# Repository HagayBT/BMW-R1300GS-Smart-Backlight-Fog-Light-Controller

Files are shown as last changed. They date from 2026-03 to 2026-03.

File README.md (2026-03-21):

# BMW R1300GS Smart Backlight & Fog Light Controller — EasierCan v2.0

A fully custom, CAN-bus-integrated lighting controller for the BMW R1300GS motorcycle. Reads factory CAN bus signals directly from the XDWA connector to control rear LED strips, fog lights, and an air horn — no wire cutting or relay splicing into the original harness.

Fully configurable over Bluetooth using a mobile-friendly Web Bluetooth UI — no app install required.

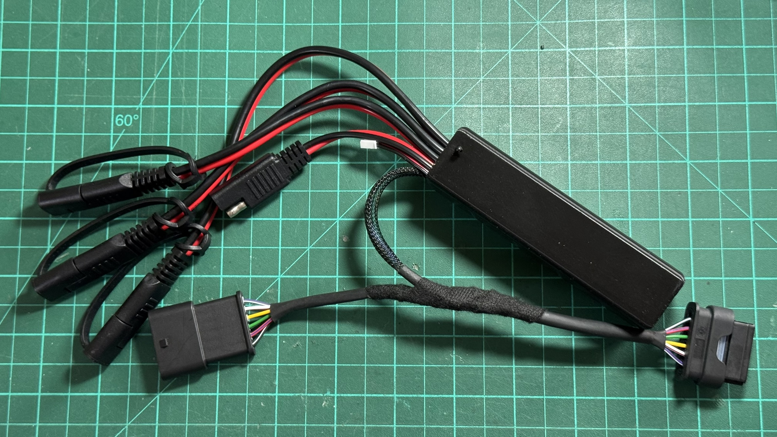
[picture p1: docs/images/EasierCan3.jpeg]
Project Banner


---

## ✨ Features

### Lighting & Outputs
- **Configurable LED strips** — 9× SK6812 RGBW LEDs per side, split into independent brake zone (first N LEDs) and indicator zone (remaining LEDs)
- **Configurable MOSFET outputs** — 3× isolated 12V outputs for fog lights and air horn
- **Wave sequential turn signals** — indicator LEDs fill sequentially left-to-right in amber
- **Blink turn signals** — standard ~1.5 Hz amber flash (50% duty cycle)
- **Brake light** — brake zone shows dim red at idle, full bright red when braking
- **Strobe mode** — triggered by triple high-beam flash within a configurable window
- **Startup animations** — 10 selectable boot animations (Night Rider, Split/BMW Sweep, Converge & Explode, Heartbeat, Comet/Meteor, Stack/Tetris, Twinkle Fade-In, Thunder, Breathe/Pulse, Ping Pong)

### Configuration
- **BLE wireless configuration** — connect from Chrome on any phone or desktop, no app needed
- **Per-output triggers** — each output has two independent event slots (ev1 / ev2), each with its own trigger, action, and delay
- **Configurable actions** — None, On, Off, Strobe, Blink; plus Wave for LED strips
- **Configurable triggers** — Brake, Signal Left, Signal Right, High Beam, Engine Running, Power On, Hazard, High Beam ×3, Horn
- **Configurable delay** — action starts only after trigger has been active for N seconds
- **NVS persistence** — all settings survive power loss, stored in ESP32 flash
- **Auto-read on connect** — UI loads device config automatically when BLE connects

### Diagnostics
- **Test Events panel** — simulate any CAN signal from the UI without touching the bike
- **Serial diagnostics** — 2-second heartbeat via USB: CAN state, RPM, error counters, signal states
- **CAN bus isolated** — listen-only mode, never transmits to the bus

---

## 🧰 Bill of Materials

| # | Component | Notes |
|---|---|---|
| 1 | Arduino Nano ESP32 | Main controller (ESP32-S3) |
| 1 | SN65HVD230 CAN Bus Transceiver | 3.3V logic, connects to XDWA |
| 1 | 872-861-501 6P OBD Connector (BMW/VW/MB) | Plugs into R1300GS XDWA port |
| 1 | DC-DC Buck Converter 5V–30V → 5V 3A | Powers Arduino + LEDs from 12V bike battery |
| 3 | LR7843 Isolated MOSFET Module (HW-532B) | Fog light left, fog light right, air horn |
| 18 | SK6812 RGBW LED (addressable) | 9 per side, rear tail/turn strip |
| 1 | Silicone Wire 22 AWG | All signal and power wiring |
| 3 | 3D Printed Parts | BackLightBody, BackLightRod, BackLightScreen |

---

## 📐 Wiring Diagram

### System Overview

```
BMW R1300GS XDWA Connector          Controller Box
  │
  ├── Pin 2  (Ground) ─────────────► Common GND (Buck IN– / Arduino GND / SN65HVD230 GND)
  ├── Pin 3  (12V ACC) ────────────► DC-DC Buck Converter IN+
  ├── Pin 4  (CAN Low) ────────────► SN65HVD230 CANL
  └── Pin 5  (CAN High) ───────────► SN65HVD230 CANH
                                          │
                              SN65HVD230 TX/RX
                                          │
                                    Arduino Nano ESP32  ◄── Buck OUT+ 5V
                                          │
                        ┌─────────────────┼─────────────────┐
                        ▼                 ▼                  ▼
                  MOSFET #1          MOSFET #2          MOSFET #3
                  Fog Light LEFT     Air Horn           Fog Light RIGHT
                        │                                    │
                        ▼                                    ▼
                   Fog Light L                         Fog Light R

            ┌─────────────────────────────────┐
            ▼                                 ▼
     LED Strip LEFT                   LED Strip RIGHT
     (9× SK6812 RGBW)                (9× SK6812 RGBW)
     D3 / GPIO_6                     D5 / GPIO_8
```

### Arduino Nano ESP32 Pin Assignment

| Arduino Pin | GPIO | Connected To |
|---|---|---|
| D4 | GPIO_7 | SN65HVD230 TX (CAN TX) |
| D6 | GPIO_9 | SN65HVD230 RX (CAN RX) |
| A1 | GPIO_2 | MOSFET #1 — Fog Light RIGHT (PWM in) |
| A5 | GPIO_12 | MOSFET #2 — Fog Light LEFT (PWM in) |
| A3 | GPIO_4 | MOSFET #3 — Air Horn (PWM in) |
| D3 | GPIO_6 | SK6812 Data — LEFT strip |
| D5 | GPIO_8 | SK6812 Data — RIGHT strip |

### MOSFET Module Wiring (each of 3 modules)

| MOSFET Terminal | Connect To |
|---|---|
| **PWM** (signal) | Arduino output pin (see table above) |
| **GND** (signal) | Arduino GND |
| **+** (load) | Motorcycle 12V positive |
| **LOAD** | Fog light / horn positive wire |
| **–** (load) | Motorcycle chassis ground |

> The fog light / horn negative wire also connects to chassis ground directly.
> Signal GND and Load GND are **isolated** by the onboard optocoupler — this is intentional.

### XDWA Connector Pinout (BMW R1300GS)

The 6P XDWA connector is the only connection needed to the bike. Use the 872-861-501 mating connector.

| Pin | Signal | Voltage | Used |
|-----|---|---|---|
| 1 | 12V Constant | 12V | — (not used) |
| 2 | Ground | 0V | ✅ Common ground |
| 3 | 12V ACC (after ignition switch) | 12V | ✅ Power input |
| 4 | CAN Low | ~2.7V | ✅ CAN bus |
| 5 | CAN High | ~2.3V | ✅ CAN bus |
| 6 | Empty | — | — |

> ⚠️ Note: CAN High/Low voltages on this bike are inverted from typical convention (High ~2.3V, Low ~2.7V). If you see no CAN traffic, try swapping CANH/CANL wires first.

### SN65HVD230 CAN Transceiver Wiring

| Transceiver Pin | Connect To |
|---|---|
| VCC | Arduino 3.3V output |
| GND | XDWA Pin 2 (common ground) |
| TX | Arduino D4 (GPIO_7) |
| RX | Arduino D6 (GPIO_9) |
| CANH | XDWA Pin 5 |
| CANL | XDWA Pin 4 |

> The SN65HVD230 runs at 3.3V logic and is directly compatible with the ESP32. Power it from the Arduino's **3.3V output pin**, not from the buck converter.
> Do **not** add a 120Ω termination resistor — the bike's bus is already terminated.

### DC-DC Buck Converter Wiring

| Buck Converter | Connect To |
|---|---|
| IN+ | XDWA Pin 3 (12V ACC) |
| IN– | XDWA Pin 2 (Ground) |
| OUT+ (5V) | Arduino 5V pin + SK6812 strip 5V power |
| OUT– | Arduino GND + SK6812 strip GND |

> Set the output to **5V** before connecting anything. The SK6812 strips and Arduino Nano ESP32 both run on 5V.

---

## 📡 CAN Bus Messages (BMW R1300GS)

These CAN IDs were identified on the R1300GS XDWA connector at **500 kbps**.

| CAN ID | Purpose | Relevant Byte/Bit |
|---|---|---|
| `0x10C` | Engine RPM (BMSK module) | `(data[2]×256 + data[1]) / 4` = RPM |
| `0x2D0` | High beam flash | Byte 6, bit 4 = 0 when flashed |
| `0x2D2` | Switches | Byte 0, bit 2 = Left signal |
| | | Byte 0, bit 3 = Right signal |
| | | Byte 0, bit 5 = Brake |

> ⚠️ These IDs were reverse-engineered on a specific R1300GS. Confirm with a CAN scanner on your own bike before trusting them. They may vary by model year or spec.

---

## 💡 LED Strip Layout

Each side has **9× SK6812 RGBW LEDs**, split into two independently controlled zones (counts are configurable):

```
[ 0 ][ 1 ][ 2 ]       — Brake Zone  (default 3 LEDs, controlled by Event 1)
[ 3 ][ 4 ][ 5 ][ 6 ][ 7 ][ 8 ] — Indicator Zone (remaining LEDs, controlled by Event 2)
```

**Brake zone default behavior:** dim red `(60, 0, 0, 0)` at idle → full red `(255, 0, 0, 0)` when brake trigger fires
**Indicator zone default behavior:** amber sequential wave `(255, 50, 0, 0)` when signal trigger fires

---

## ⚙️ Output Configuration

Each of the 5 outputs has **two independent event slots** (Ev1 / Ev2). Each slot configures:

| Field | Options |
|---|---|
| **Trigger** | None, Brake, Signal Left, Signal Right, High Beam, Engine Running, Power On, Hazard, High Beam ×3, Horn |
| **Action** | None, On, Off, Blink, Strobe, Wave *(LED strips only)* |
| **Delay** | 0, 1, 2, 4, 8, 16, 32, 64, 128 seconds |

For **LED strips**: Ev1 drives the brake zone, Ev2 drives the indicator zone independently.
For **12V MOSFET outputs**: Ev2 takes priority over Ev1 when both triggers are active.

### Default Output Configuration

| Output | Function | Ev1 Trigger | Ev1 Action | Ev1 Delay | Ev2 Trigger | Ev2 Action | Ev2 Delay |
|---|---|---|---|---|---|---|---|
| LED Left Strip | LED Strip | Brake | On | 0s | Signal Left | Wave | 0s |
| LED Right Strip | LED Strip | Brake | On | 0s | Signal Right | Wave | 0s |
| 12v Output 1 | Fog Light Left | Engine Running | On | 5s | High Beam ×3 | Strobe | 0s |
| 12v Output 2 | Air Horn | Horn | On | 1s | — | — | — |
| 12v Output 3 | Fog Light Right | Engine Running | On | 5s | High Beam ×3 | Strobe | 0s |

---

## 📱 BLE Configuration UI

Open `EasierCan.html` in **Chrome** (desktop or Android) — no app install required.

### Connecting

1. Power on the controller (bike ignition on, or bench power)
2. Open `EasierCan.html` in Chrome
3. Press **Connect** and select **EasierCan** from the Bluetooth popup
4. All current device settings are loaded automatically

### Sections

| Section | Description |
|---|---|
| **Startup Sequence** | Choose the boot animation; Send/Read from device |
| **Test Events** | Simulate CAN signals (brake, signals, high beam, etc.) without the bike |
| **Output Configuration** | Configure triggers, actions, and delays per output |
| **Advanced Variables** | LED counts, RPM threshold, strobe timing, wave timing |

### Test Events Panel

| Button | Type | Simulates |
|---|---|---|
| Power On | Toggle | Runs startup animation |
| Engine Running | Toggle | Sets engine-running state |
| Hazard | Toggle | Both signals active |
| Horn | Momentary | 300ms horn pulse |
| Signal Left | Hold | Left signal while held |
| High Beam | Hold | High beam while held |
| Brake | Hold | Brake signal while held |
| Signal Right | Hold | Right signal while held |

---

## 🚀 Startup Animations

| # | Name | Description |
|---|---|---|
| 0 | None | No animation |
| 1 | Random | Picks one of the below at random |
| 2 | Night Rider | Red scanner sweep (Knight Rider style) |
| 3 | Split / BMW Sweep | Warm-white comet sweeps outward from center |
| 4 | Converge & Explode | Amber heads race to center, then white burst |
| 5 | Heartbeat | Lub-dub red pulse × 3 |
| 6 | Comet / Meteor | Warm-white head with long amber-to-red tail |
| 7 | Stack (Tetris) | LEDs shoot and stack into a red column |
| 8 | Twinkle Fade-In | Random warm-white sparkles solidify to red |
| 9 | Thunder | Random white flashes, then dim red bloom |
| 10 | Breathe / Pulse | Slow sine-like red fade × 3 cycles |
| 11 | Ping Pong | Orange dot bounces end-to-end, accelerating |

---

## 🛠️ Software Setup

### Dependencies

Install via Arduino Library Manager:

- [`Adafruit NeoPixel`](https://github.com/adafruit/Adafruit_NeoPixel)
- [`ArduinoBLE`](https://github.com/arduino-libraries/ArduinoBLE)
- [`ArduinoJson`](https://arduinojson.org/) (>= 6.21)
- ESP32 Arduino Core by Espressif (includes `driver/twai.h` — no separate install needed)

### Board Setup

1. Install **Arduino ESP32 core** in Arduino IDE (Board Manager → search "esp32" by Espressif)
2. Select board: **Arduino Nano ESP32**
3. Upload `EasierCan/EasierCan.ino`

### First Boot

Open Serial Monitor at **115200 baud**. You will see:

```
========================================
     BMW R1300GS  —  EasierCan  v2
========================================
[NVS] No saved config — using defaults.
[BLE] Advertising as "EasierCan"
```

Every 2 seconds a diagnostic report prints:

```
--- DIAGNOSTIC ---
CAN msg/2s: 847
RX errors:  0
CAN state:  RUNNING
RPM: 1250  Eng: ON  Str: off  Brk: off  L: off  R: off  Horn: off
[BLE] Advertising
------------------
```

If `CAN msg/2s: 0` appears, check wiring and ensure ignition is ON.

---

## 🔒 Safety Notes

- This device **reads** CAN bus only — it never transmits. It cannot interfere with bike ECU operation.
- Always fuse the 12V input line (suggest 5A inline fuse).
- The LR7843 MOSFET modules support up to 15A continuous — more than enough for fog lights and a horn.
- Test all connections on the bench before installing on the bike.
- Use the **Test Events** panel in the UI to verify output behaviour on the bench.

---

## 📁 Repository Structure

```
/
├── EasierCan/
│   ├── EasierCan.ino       # Main Arduino sketch
│   └── EasierCan.html      # Web Bluetooth configuration UI (open in Chrome)
├── README.md
├── STL/
│   ├── BackLightBody.stl
│   ├── BackLightRod.stl
│   └── BackLightScreen.stl
└── docs/
    └── images/
```

---

## 📜 License

MIT License — free to use, modify, and share. Credit appreciated!

---

## 🙏 Contributing

Found a different CAN ID on your R1300GS? Discovered a bug? PRs and Issues are welcome!

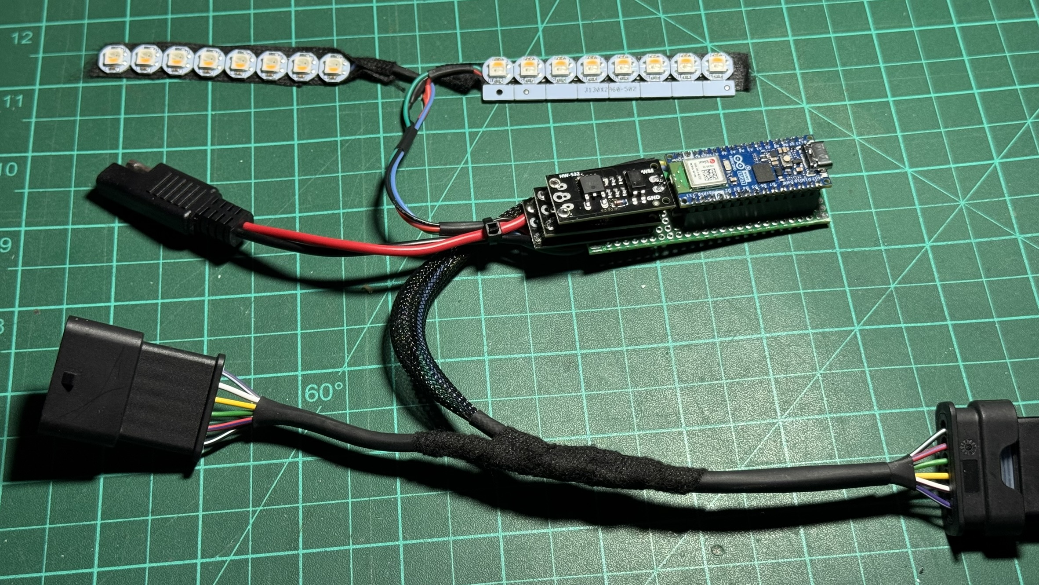
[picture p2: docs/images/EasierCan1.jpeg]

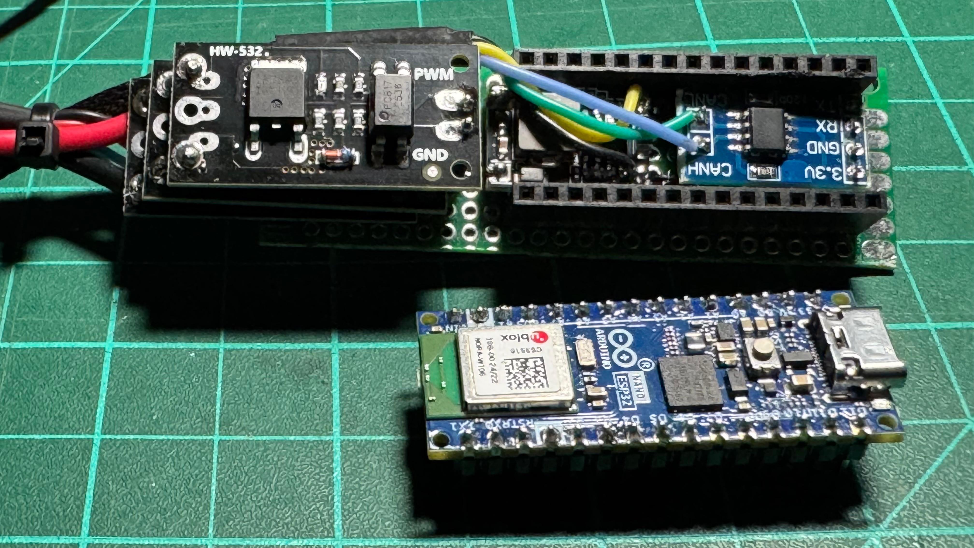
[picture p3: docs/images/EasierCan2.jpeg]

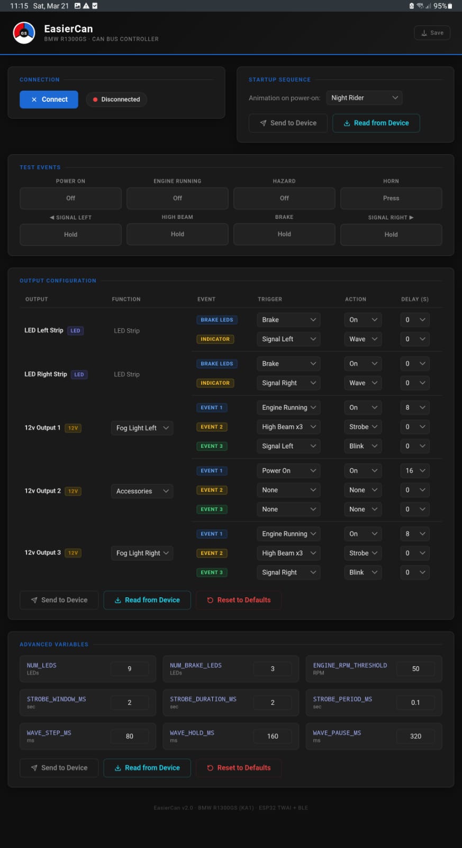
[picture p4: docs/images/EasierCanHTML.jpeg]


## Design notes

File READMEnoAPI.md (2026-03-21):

# BMW R1300GS Smart Backlight & Fog Light Controller

A fully custom, CAN-bus-integrated lighting controller for the BMW R1300GS motorcycle. Reads factory CAN bus signals directly from the XDWA connector to control rear LED strips, fog lights, and an air horn — no wire cutting or relay splicing into the original harness.

Project Banner

---

## ✨ Features

- **Wave-style sequential turn signals** — 9× SK6812 RGBW LEDs per side, filling left-to-right/right-to-left in sequence
- **Brake light** — first 3 LEDs on each strip dim red at idle, full bright red when braking
- **Fog light control** — left and right fog lights via MOSFET switches, auto-enable 10 seconds after engine start
- **Fog turn-signal blink** — fog lights blink in sync with the active turn signal
- **Emergency strobe** — triple-press the high-beam flash to trigger a 5-second full strobe on both fog lights
- **Air horn output** — third MOSFET reserved for future air horn
- **Knight Rider startup animation** — red sweep across all 18 LEDs on boot
- **Serial diagnostics** — 2-second heartbeat report via USB: CAN bus health, error counters, state summary
- **CAN bus isolated** — uses SN65HVD230 transceiver; reads-only, never writes to the bus

---

## 🧰 Bill of Materials

| # | Component | Notes |
|---|---|---|
| 1 | Arduino Nano ESP32 | Main controller |
| 1 | SN65HVD230 CAN Bus Transceiver | 3.3V logic, connects to XDWA |
| 1 | 872-861-501 6P OBD Connector (BMW/VW/MB) | Plugs into R1300GS XDWA port |
| 1 | DC-DC Buck Converter 5V–30V → 5V 3A | Powers Arduino + LEDs from 12V bike battery |
| 3 | LR7843 Isolated MOSFET Module (HW-532B) | Fog light left, fog light right, air horn |
| 18 | SK6812 RGBW LED (addressable) | 9 per side, rear tail/turn strip |
| 1 | Silicone Wire 22 AWG | All signal and power wiring |
| 3 | 3D Printed Parts | BackLightBody, BackLightRod, BackLightScreen |

---

## 📐 Wiring Diagram

### System Overview

```
BMW R1300GS XDWA Connector          Controller Box
  │
  ├── Pin 2  (Ground) ─────────────► Common GND (Buck IN– / Arduino GND / SN65HVD230 GND)
  ├── Pin 3  (12V ACC) ────────────► DC-DC Buck Converter IN+
  ├── Pin 4  (CAN Low) ────────────► SN65HVD230 CANL
  └── Pin 5  (CAN High) ───────────► SN65HVD230 CANH
                                          │
                              SN65HVD230 TX/RX
                                          │
                                    Arduino Nano ESP32  ◄── Buck OUT+ 5V
                                          │
                        ┌─────────────────┼─────────────────┐
                        ▼                 ▼                  ▼
                  MOSFET #1          MOSFET #2          MOSFET #3
                  Fog Light LEFT     Fog Light RIGHT     Air Horn
                        │                 │
                        ▼                 ▼
                   Fog Light L       Fog Light R
                                          
            ┌─────────────────────────────────┐
            ▼                                 ▼
     LED Strip LEFT                   LED Strip RIGHT
     (9× SK6812 RGBW)                (9× SK6812 RGBW)
     D3 / GPIO_6                     D5 / GPIO_8
```

### Arduino Nano ESP32 Pin Assignment

| Arduino Pin | GPIO | Connected To |
|---|---|---|
| D4 | GPIO_7 | SN65HVD230 TX (CAN TX) |
| D6 | GPIO_9 | SN65HVD230 RX (CAN RX) |
| A1 | GPIO_2 | MOSFET #1 — Fog Light RIGHT (PWM in) |
| A5 | GPIO_3 | MOSFET #2 — Fog Light LEFT (PWM in) |
| A3 | GPIO_4 | MOSFET #3 — Air Horn (PWM in) |
| D3 | GPIO_6 | SK6812 Data — LEFT strip |
| D5 | GPIO_8 | SK6812 Data — RIGHT strip |

### MOSFET Module Wiring (each of 3 modules)

| MOSFET Terminal | Connect To |
|---|---|
| **PWM** (signal) | Arduino output pin (see table above) |
| **GND** (signal) | Arduino GND |
| **+** (load) | Motorcycle 12V positive |
| **LOAD** | Fog light / horn positive wire |
| **–** (load) | Motorcycle chassis ground |

> The fog light / horn negative wire also connects to chassis ground directly.
> Signal GND and Load GND are **isolated** by the onboard optocoupler — this is intentional.

### XDWA Connector Pinout (BMW R1300GS)

The 6P XDWA connector is the only connection needed to the bike. Use the 872-861-501 mating connector.

| Pin | Signal | Voltage | Used |
|-----|---|---|---|
| 1 | 12V Constant | 12V | — (not used) |
| 2 | Ground | 0V | ✅ Common ground |
| 3 | 12V ACC (after ignition switch) | 12V | ✅ Power input |
| 4 | CAN Low | ~2.7V | ✅ CAN bus |
| 5 | CAN High | ~2.3V | ✅ CAN bus |
| 6 | Empty | — | — |

> ⚠️ Note: CAN High/Low voltages on this bike are inverted from typical convention (High ~2.3V, Low ~2.7V). If you see no CAN traffic, try swapping CANH/CANL wires first.

### XDWA → Controller Connections (as wired)

| XDWA Pin | Signal | Connect To |
|---|---|---|
| Pin 2 | Ground | DC-DC Buck IN– **and** Arduino GND **and** SN65HVD230 GND |
| Pin 3 | 12V ACC | DC-DC Buck IN+ |
| Pin 4 | CAN Low | SN65HVD230 CANL |
| Pin 5 | CAN High | SN65HVD230 CANH |

### SN65HVD230 CAN Transceiver Wiring

| Transceiver Pin | Connect To |
|---|---|
| VCC | Arduino 3.3V output |
| GND | XDWA Pin 2 (common ground) |
| TX | Arduino D4 (GPIO_7) |
| RX | Arduino D6 (GPIO_9) |
| CANH | XDWA Pin 5 |
| CANL | XDWA Pin 4 |

> The SN65HVD230 runs at 3.3V logic and is directly compatible with the ESP32. Power it from the Arduino's **3.3V output pin**, not from the buck converter.
> Do **not** add a 120Ω termination resistor — the bike's bus is already terminated. If you see RX errors, try swapping CANH/CANL or adding one and see if it improves.

### DC-DC Buck Converter Wiring

| Buck Converter | Connect To |
|---|---|
| IN+ | XDWA Pin 3 (12V ACC) |
| IN– | XDWA Pin 2 (Ground) |
| OUT+ (5V) | Arduino 5V pin + SK6812 strip 5V power |
| OUT– | Arduino GND + SK6812 strip GND |

> Set the output to **5V** before connecting anything. The SK6812 strips and Arduino Nano ESP32 both run on 5V.
> Using ACC (Pin 3) means the controller powers on with the ignition — no need for a separate switch.

---

## 📡 CAN Bus Messages (BMW R1300GS)

These CAN IDs were identified on the R1300GS XDWA connector at **500 kbps**.

| CAN ID | Purpose | Relevant Byte/Bit |
|---|---|---|
| `0x3FA` | Engine state | Byte 5 > 0 = engine running |
| `0x2D0` | High beam flash | Byte 6, bit 4 = 0 when flashed |
| `0x2D2` | Switches | Byte 0, bit 2 = Left signal |
| | | Byte 0, bit 3 = Right signal |
| | | Byte 0, bit 5 = Brake |

> ⚠️ These IDs were reverse-engineered on a specific R1300GS. Confirm with a CAN scanner on your own bike before trusting them. They may vary by model year or spec.

---

## 💡 LED Strip Layout

Each side has **9× SK6812 RGBW LEDs**, indexed 0–8:

```
[ 0 ][ 1 ][ 2 ] — Tail / Brake LEDs (always on)
[ 3 ][ 4 ][ 5 ][ 6 ][ 7 ][ 8 ] — Turn Signal LEDs (Wave sequential)
```

**Tail mode:** dim red `(60, 0, 0, 0)`  
**Brake mode:** full red `(255, 0, 0, 0)`  
**Turn signal:** amber sequential fill `(255, 50, 0, 0)`, 80ms per step, 160ms hold, 320ms pause

---

## 🔆 Fog Light Behavior

| Condition | Fog Light State |
|---|---|
| Engine off | OFF |
| Engine on < 10 seconds | OFF (startup delay) |
| Engine on ≥ 10 seconds | ON |
| Engine on + turn signal active | Blink at 800ms cycle |
| Triple high-beam flash | 5-second strobe (10Hz) on both fogs |

---

## 🖨️ 3D Printed Parts

All STL files are in the `/STL` folder.

| File | Description |
|---|---|
| `BackLightBody.stl` | Main housing body |
| `BackLightRod.stl` | Mounting rod / arm |
| `BackLightScreen.stl` | LED diffuser screen |

Print recommendations: PETG or ASA for outdoor/UV resistance. 20–30% infill. No supports needed for Body and Screen; Rod may need supports depending on orientation.

---

## 🛠️ Software Setup

### Dependencies

Install via Arduino Library Manager or PlatformIO:

- [`Adafruit NeoPixel`](https://github.com/adafruit/Adafruit_NeoPixel)
- ESP32 Arduino Core (includes `driver/twai.h` — no separate install needed)

### Board Setup

1. Install **Arduino ESP32 core** in Arduino IDE (Board Manager → search "esp32" by Espressif)
2. Select board: **Arduino Nano ESP32**
3. Upload `EasierCan.ino.ino`

### First Boot

Open Serial Monitor at **115200 baud**. You will see:

```
========================================
  BMW R1300GS CONTROLLER - DIAGNOSTICS
========================================
Initializing CAN Driver... SUCCESS! Driver Running.
```

Every 2 seconds a diagnostic report prints showing CAN message count, error counters, and current state. If `CAN Messages Received: 0` appears, check wiring and ensure ignition is ON.

---

## 🔒 Safety Notes

- This device **reads** CAN bus only — it never transmits. It cannot interfere with bike ECU operation.
- Always fuse the 12V input line (suggest 5A inline fuse).
- The LR7843 MOSFET modules support up to 15A continuous — more than enough for fog lights and a horn.
- Test all connections on the bench before installing on the bike.
- The fog lights auto-enable 10 seconds after engine start. Ensure fog lights are properly mounted before first test.

---

## 📁 Repository Structure

```
/
├── EasierCan.ino.ino          # Main Arduino sketch
├── README.md              # This file
├── STL/
│   ├── BackLightBody.stl
│   ├── BackLightRod.stl
│   └── BackLightScreen.stl
└── docs/
    └── images/
```

---

## 📜 License

MIT License — free to use, modify, and share. Credit appreciated!

---

## 🙏 Contributing

Found a different CAN ID on your R1300GS? Discovered a bug? PRs and Issues are welcome!

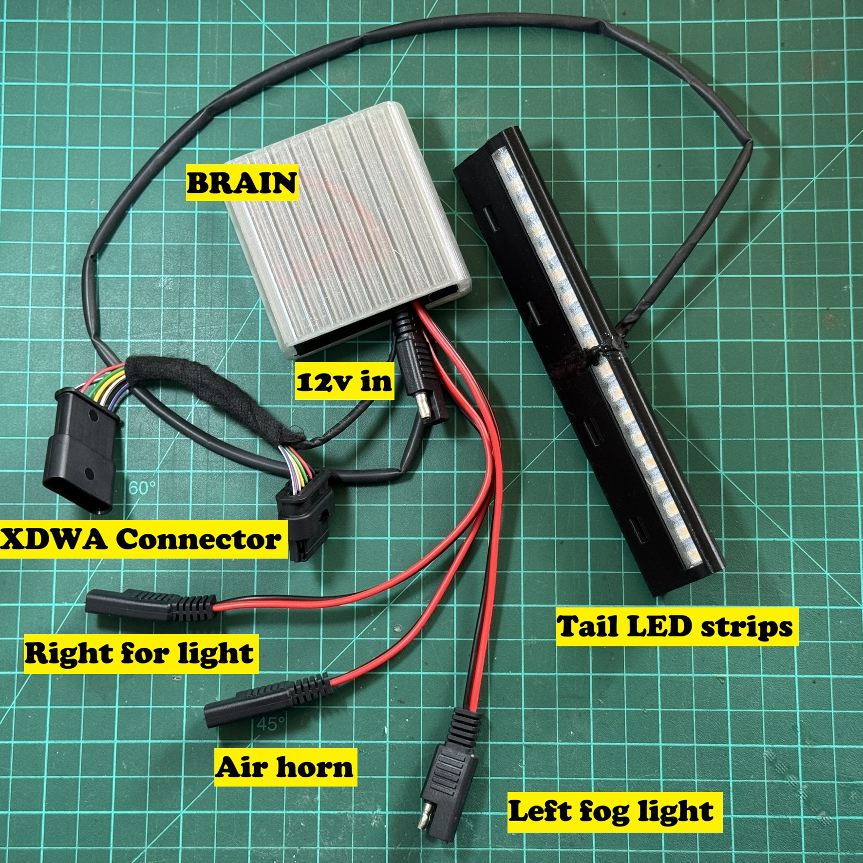
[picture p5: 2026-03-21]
docs/images/easiercanNoAPI.jpg

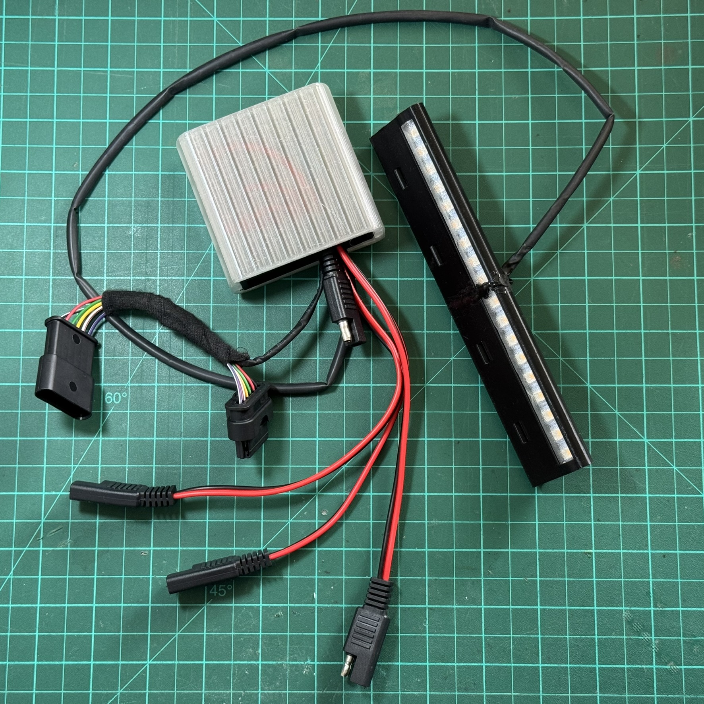
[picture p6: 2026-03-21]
docs/images/easiercan2NoAPI.jpg

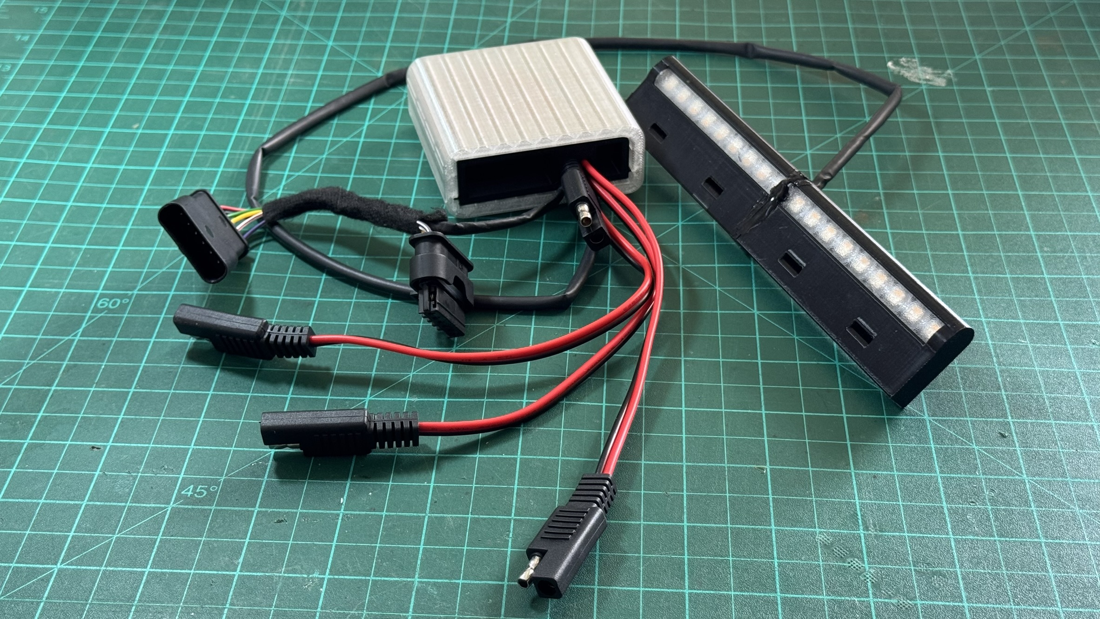
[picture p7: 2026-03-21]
docs/images/easiercan1NoAPI.jpg

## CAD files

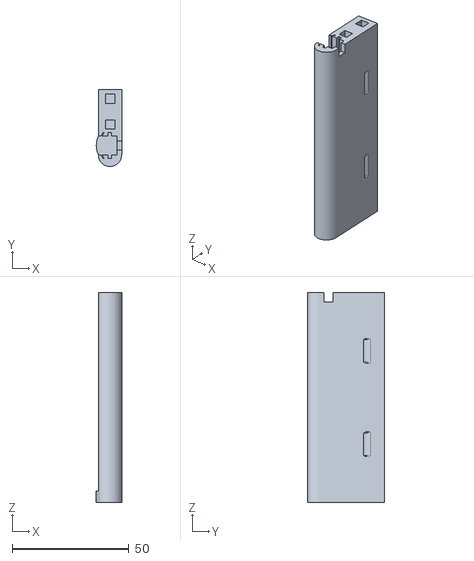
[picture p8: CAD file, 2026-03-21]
STL/BackLightBody.stl
10.9 x 33.0 x 90.0

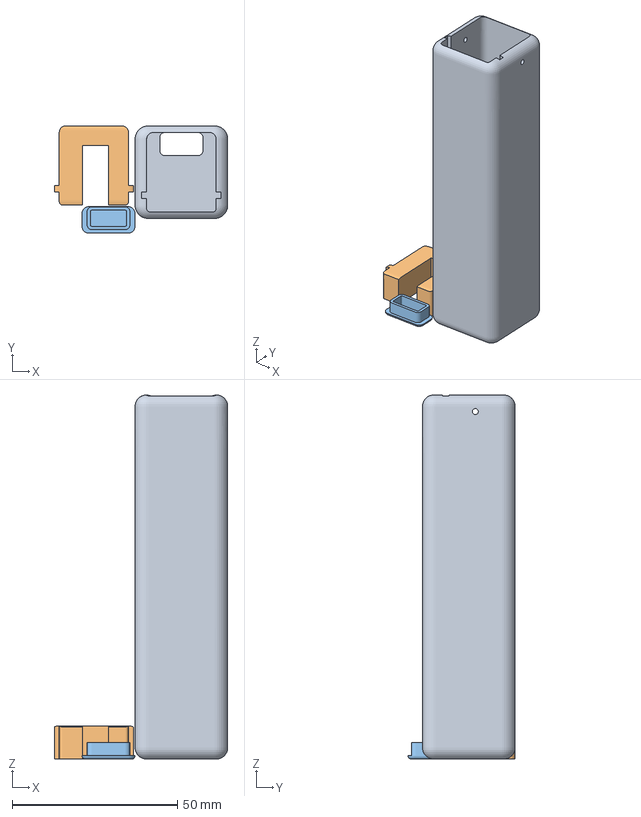
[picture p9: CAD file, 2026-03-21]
STL/EasierCanUSB.3mf
52.4 x 32.4 x 110.0 mm
EasierCanBody.stl
EasierCanCover.stl
EasierCanUSB.stl

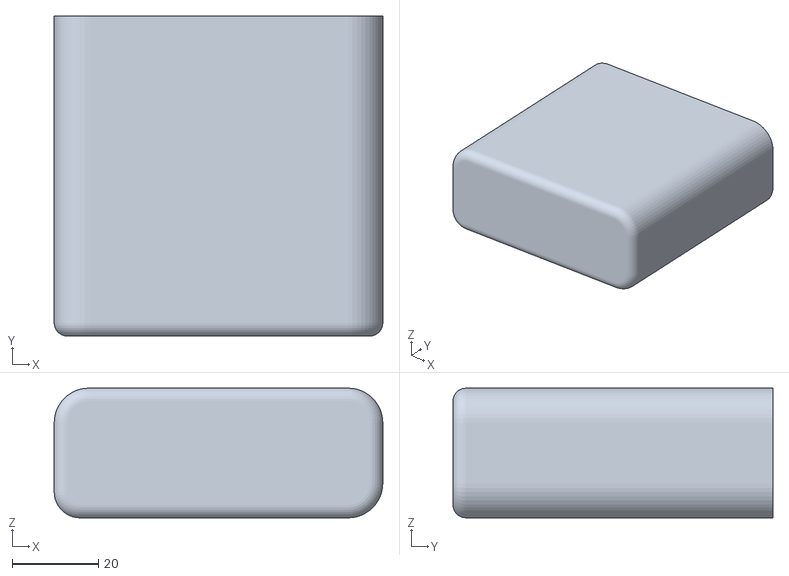
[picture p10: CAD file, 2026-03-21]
STL/EasiercanBoxNoAPI.stl
76.0 x 74.0 x 30.0

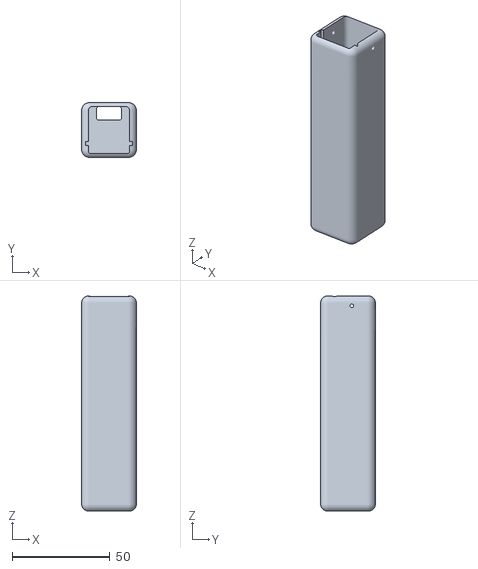
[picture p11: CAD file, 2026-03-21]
STL/EasierCanBody.stl
28.0 x 28.0 x 110.0

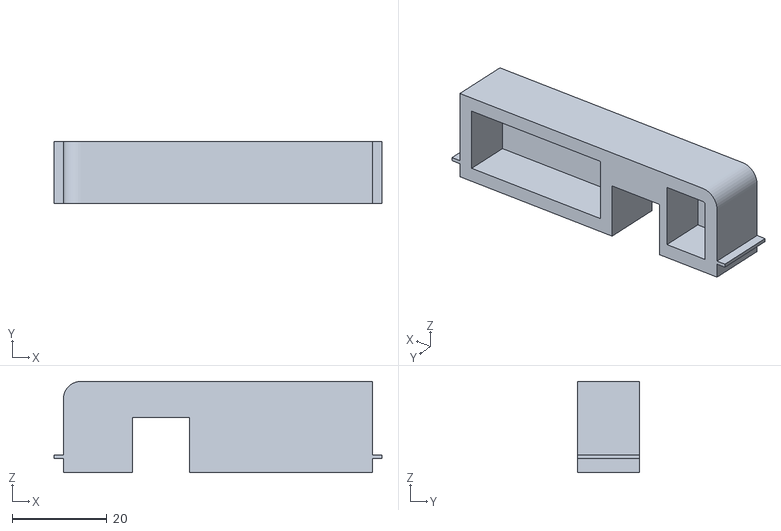
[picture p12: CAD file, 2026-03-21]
STL/EasiercanTopNoAPI.stl
69.2 x 13.0 x 19.2

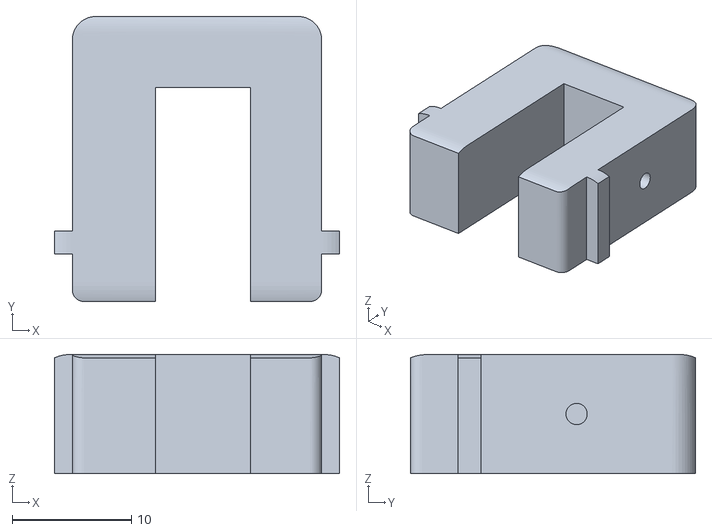
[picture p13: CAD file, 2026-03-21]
STL/EasierCanCover.stl
23.9 x 23.9 x 10.0

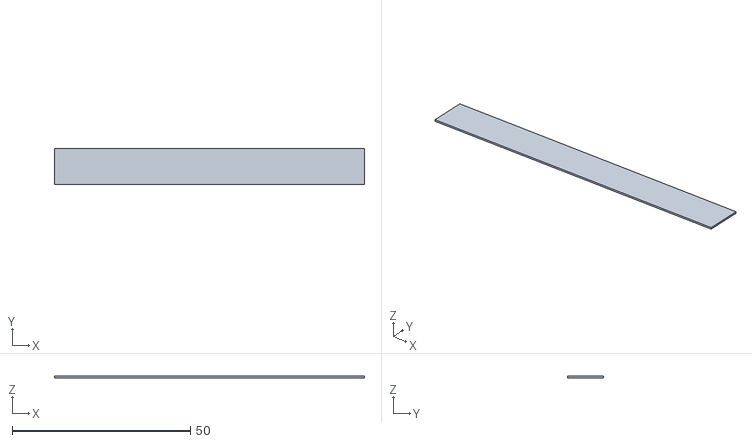
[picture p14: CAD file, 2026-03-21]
STL/BackLightScreen.stl
87.0 x 10.0 x 0.45

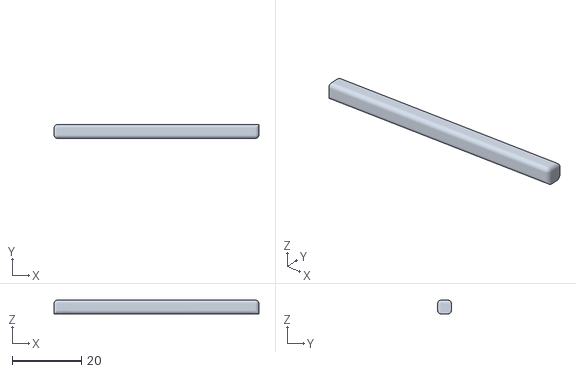
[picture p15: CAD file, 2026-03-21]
STL/BackLightRod.stl
59.0 x 3.95 x 3.95

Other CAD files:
STL/EasierCanUSB.stl

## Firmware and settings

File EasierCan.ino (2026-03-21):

// ============================================================
//  EasierCan.ino  —  BMW R1300GS CAN Bus Controller  v2.0
//  Arduino Nano ESP32 (ESP32-S3)
//
//  NEW in v2: BLE configuration + NVS persistence
//
//  Required libraries (Arduino Library Manager):
//    • Adafruit NeoPixel
//    • ArduinoBLE
//    • ArduinoJson  (>= 6.21)
// ============================================================

#include <Adafruit_NeoPixel.h>
#include "driver/twai.h"
#include <ArduinoBLE.h>
#include <Preferences.h>
#include <ArduinoJson.h>

// ──────────────────────────────────────────────────────────
// HARDWARE PINS  — Arduino Nano ESP32
// ──────────────────────────────────────────────────────────
#define RX_PIN        GPIO_NUM_9   // D6
#define TX_PIN        GPIO_NUM_7   // D4
#define LED_PIN_LEFT  6            // D3
#define LED_PIN_RIGHT 8            // D5
#define FOG_LEFT_PIN  A5           // GPIO 12
#define FOG_RIGHT_PIN A1           // GPIO 2
#define AIR_HORN_PIN  A3           // GPIO 4

// ──────────────────────────────────────────────────────────
// BLE
// ──────────────────────────────────────────────────────────
#define BLE_DEVICE_NAME  "EasierCan"
#define BLE_SERVICE_UUID "FFE0"
#define BLE_CHAR_UUID    "FFE1"

// ──────────────────────────────────────────────────────────
// CAN IDs
// ──────────────────────────────────────────────────────────
// 0x10C — BMSK engine module, 10ms cycle
//   RPM = (data[2]*256 + data[1]) / 4
#define ID_BMSK      0x10C
#define ID_HIGH_BEAM 0x2D0
#define ID_SWITCHES  0x2D2

// ──────────────────────────────────────────────────────────
// CONFIG — lookup tables (indices must match HTML dropdowns)
// ──────────────────────────────────────────────────────────
// FUNCTIONS: 0=None 1=LED Strip 2=Fog Light Left 3=Fog Light Right
//            4=Air Horn 5=Accessories 6=Brake Light
// EVENTS:    0=None 1=Brake 2=Signal Left 3=Signal Right 4=High Beam
//            5=Engine Running 6=Power On 7=Hazard 8=High Beam x3 9=Horn
// ACTIONS:   0=None 1=On 2=Off 3=Wave 4=Strobe 5=Blink

const char* FUNC_NAMES[] = {
  "None","LED Strip","Fog Light Left","Fog Light Right",
  "Air Horn","Accessories","Brake Light"
};
const char* TRIG_NAMES[] = {
  "None","Brake","Signal Left","Signal Right","High Beam",
  "Engine Running","Power On","Hazard","High Beam x3","Horn"
};
const char* ACT_NAMES[] = { "None","On","Off","Wave","Strobe","Blink" };

uint8_t nameToIdx(const char** table, uint8_t tableLen, const char* name) {
  for (uint8_t i = 0; i < tableLen; i++)
    if (strcmp(table[i], name) == 0) return i;
  return 0;
}
#define FUNC_IDX(n) nameToIdx(FUNC_NAMES, 7, n)
#define TRIG_IDX(n) nameToIdx(TRIG_NAMES, 10, n)
#define ACT_IDX(n)  nameToIdx(ACT_NAMES,  6, n)

// ──────────────────────────────────────────────────────────
// CONFIG STRUCT
// ──────────────────────────────────────────────────────────
struct EventRule  { uint8_t trigger, action, delaySec; };
struct OutputConf { uint8_t func; EventRule ev1, ev2; };

struct Cfg {
  uint8_t    startupSeq;
  OutputConf outputs[5];
  uint8_t    numLeds;
  uint8_t    numBrakeLeds;
  uint16_t   engineRpmThr;
  float      strobeWindowSec;
  float      strobeDurSec;
  float      strobePeriodSec;
  uint16_t   waveStepMs;
  uint16_t   waveHoldMs;
  uint16_t   wavePauseMs;
  char       pin[5];        // 4-digit BLE PIN, null-terminated (default "0000")
} cfg;

void cfgSetDefaults() {
  cfg.startupSeq      = 2;   // Night Rider

  // LED Left Strip  — Brake→On  |  Signal Left→Wave
  cfg.outputs[0] = { 1, {1,1,0}, {2,3,0} };
  // LED Right Strip — Brake→On  |  Signal Right→Wave
  cfg.outputs[1] = { 1, {1,1,0}, {3,3,0} };
  // 12v Output 1 (Fog Light Left)  — Engine Running→On(8s) | HBx3→Strobe
  cfg.outputs[2] = { 2, {5,1,8}, {8,4,0} };
  // 12v Output 2 (Accessories)     — Power On→On(16s) | —
  cfg.outputs[3] = { 5, {6,1,16}, {0,0,0} };
  // 12v Output 3 (Fog Light Right) — Engine Running→On(8s) | HBx3→Strobe
  cfg.outputs[4] = { 3, {5,1,8}, {8,4,0} };

  cfg.numLeds          = 9;
  cfg.numBrakeLeds     = 3;
  cfg.engineRpmThr     = 50;
  cfg.strobeWindowSec  = 2.0;
  cfg.strobeDurSec     = 2.0;
  cfg.strobePeriodSec  = 0.1;
  cfg.waveStepMs       = 80;
  cfg.waveHoldMs       = 160;
  cfg.wavePauseMs      = 320;
  strncpy(cfg.pin, "0000", 5);
}

// ──────────────────────────────────────────────────────────
// NVS
// ──────────────────────────────────────────────────────────
Preferences prefs;

void cfgSave() {
  prefs.begin("ec", false);
  prefs.putBytes("cfg", &cfg, sizeof(cfg));
  prefs.end();
  Serial.println("[NVS] Config saved.");
}

bool cfgLoad() {
  prefs.begin("ec", true);
  bool ok = prefs.isKey("cfg") &&
            (prefs.getBytesLength("cfg") == sizeof(cfg));
  if (ok) prefs.getBytes("cfg", &cfg, sizeof(cfg));
  prefs.end();
  return ok;
}

// ──────────────────────────────────────────────────────────
// BLE OBJECTS
// ──────────────────────────────────────────────────────────
BLEService        bleService(BLE_SERVICE_UUID);
BLECharacteristic bleChar(BLE_CHAR_UUID,
  BLERead | BLEWriteWithoutResponse | BLENotify, 512);

String bleBuf = "";   // buffers partial BLE writes until '\n'

// ──────────────────────────────────────────────────────────
// NEOPIXELS  (length updated from cfg after NVS load)
// ──────────────────────────────────────────────────────────
Adafruit_NeoPixel ledsL(9, LED_PIN_LEFT,  NEO_GRBW + NEO_KHZ800);
Adafruit_NeoPixel ledsR(9, LED_PIN_RIGHT, NEO_GRBW + NEO_KHZ800);

// ──────────────────────────────────────────────────────────
// STATE
// ──────────────────────────────────────────────────────────
bool          stateLeft       = false;
bool          stateBrake      = false;
bool          stateRight      = false;
bool          stateHighBeam   = false;
bool          stateEngine     = false;
bool          stateHorn       = false;
uint16_t      engineRpm       = 0;
unsigned long engineStartTime = 0;

bool          strobeActive     = false;
unsigned long strobeEndTime    = 0;
int           hbPressCount     = 0;
unsigned long firstHBPressTime = 0;

// Per-output, per-event delay tracking (5 outputs × 2 events)
bool          prevTrigState[5][2]  = {};
unsigned long trigActiveAt[5][2]   = {};

bool          bleAuthenticated     = false;  // true after correct PIN sent

unsigned long lastDebugPrint        = 0;
unsigned int  messagesReceivedInCycle = 0;

// ──────────────────────────────────────────────────────────
// BLE SEND HELPERS
// ──────────────────────────────────────────────────────────
void sendBLE(const String& data) {
  if (!BLE.connected()) return;
  String payload = data + "\n";
  // Send in 500-byte chunks so large JSON clears BLE MTU limits
  const int CHUNK = 500;
  int pos = 0, len = payload.length();
  while (pos < len) {
    int sz = min(CHUNK, len - pos);
    bleChar.writeValue((uint8_t*)(payload.c_str() + pos), sz);
    pos += sz;
    if (pos < len) delay(30);
  }
}

void sendOutputsConfig() {
  String s = "{\"cmd\":\"outputs\",\"config\":[";
  for (int i = 0; i < 5; i++) {
    if (i) s += ",";
    s += "{\"func\":\"";  s += FUNC_NAMES[cfg.outputs[i].func];         s += "\"";
    s += ",\"ev1\":\"";   s += TRIG_NAMES[cfg.outputs[i].ev1.trigger];  s += "\"";
    s += ",\"a1\":\"";    s += ACT_NAMES [cfg.outputs[i].ev1.action];   s += "\"";
    s += ",\"d1\":";      s += cfg.outputs[i].ev1.delaySec;
    s += ",\"ev2\":\"";   s += TRIG_NAMES[cfg.outputs[i].ev2.trigger];  s += "\"";
    s += ",\"a2\":\"";    s += ACT_NAMES [cfg.outputs[i].ev2.action];   s += "\"";
    s += ",\"d2\":";      s += cfg.outputs[i].ev2.delaySec;
    s += "}";
  }
  s += "]}";
  sendBLE(s);
}

void sendAdvancedConfig() {
  String s = "{\"cmd\":\"advanced\",\"vars\":{";
  s += "\"NUM_LEDS\":"             + String(cfg.numLeds)        + ",";
  s += "\"NUM_BRAKE_LEDS\":"       + String(cfg.numBrakeLeds)   + ",";
  s += "\"ENGINE_RPM_THRESHOLD\":" + String(cfg.engineRpmThr)   + ",";
  s += "\"STROBE_WINDOW_MS\":"     + String(cfg.strobeWindowSec)+ ",";
  s += "\"STROBE_DURATION_MS\":"   + String(cfg.strobeDurSec)   + ",";
  s += "\"STROBE_PERIOD_MS\":"     + String(cfg.strobePeriodSec)+ ",";
  s += "\"WAVE_STEP_MS\":"         + String(cfg.waveStepMs)     + ",";
  s += "\"WAVE_HOLD_MS\":"         + String(cfg.waveHoldMs)     + ",";
  s += "\"WAVE_PAUSE_MS\":"        + String(cfg.wavePauseMs);
  s += "}}";
  sendBLE(s);
}

// ──────────────────────────────────────────────────────────
// BLE COMMAND HANDLER
// ──────────────────────────────────────────────────────────
void testOutputEvent(uint8_t outIdx, uint8_t evNum) {
  if (outIdx < 2) {
    // LED outputs — brief white flash
    for (int i = 0; i < cfg.numLeds; i++) {
      ledsL.setPixelColor(i, ledsL.Color(255, 255, 255, 0));
      ledsR.setPixelColor(i, ledsR.Color(255, 255, 255, 0));
    }
    ledsL.show(); ledsR.show();
    delay(500);
    ledsL.clear(); ledsR.clear();
    ledsL.show();  ledsR.show();
  } else {
    // 12v outputs — 500 ms pulse on the relevant pin
    uint8_t pin = (outIdx == 2) ? FOG_LEFT_PIN :
                  (outIdx == 3) ? AIR_HORN_PIN  : FOG_RIGHT_PIN;
    digitalWrite(pin, HIGH);
    delay(500);
    digitalWrite(pin, LOW);
  }
}

void handleBleCommand(const String& json) {
  // The outputs-config JSON is ~450 bytes; ArduinoJson copies all strings from
  // an Arduino String, so the pool must be ~2× the raw JSON size.
  // StaticJsonDocument<1024> was too small → NoMemory → cfg never updated.
  StaticJsonDocument<2048> doc;
  DeserializationError err = deserializeJson(doc, json);
  if (err) {
    Serial.print("[BLE] JSON parse ERROR: ");
    Serial.print(err.c_str());
    Serial.print("  (json len=");
    Serial.print(json.length());
    Serial.println(")");
    return;
  }

  const char* cmd = doc["cmd"] | "";
  Serial.print("[BLE] cmd="); Serial.println(cmd);

  // ── auth — must be handled before the PIN gate ──────────
  if (strcmp(cmd, "auth") == 0) {
    const char* p = doc["pin"] | "";
    bool ok = (strlen(p) == 4 && strcmp(p, cfg.pin) == 0);
    bleAuthenticated = ok;
    sendBLE(ok ? "{\"cmd\":\"auth_result\",\"ok\":true}"
               : "{\"cmd\":\"auth_result\",\"ok\":false}");
    Serial.println(ok ? "[BLE] Authenticated." : "[BLE] Auth FAILED — wrong PIN.");
    return;
  }

  // ── PIN gate — reject every other command until authenticated
  if (!bleAuthenticated) {
    sendBLE("{\"cmd\":\"auth_result\",\"ok\":false}");
    Serial.println("[BLE] Command rejected — not authenticated.");
    return;
  }

  // ── startup ────────────────────────────────────────────
  if (strcmp(cmd, "startup") == 0) {
    cfg.startupSeq = doc["value"] | cfg.startupSeq;
    cfgSave();
  }
  // ── test_startup ───────────────────────────────────────
  else if (strcmp(cmd, "test_startup") == 0) {
    runStartupAnimation(doc["value"] | 2);
  }
  // ── outputs config ─────────────────────────────────────
  else if (strcmp(cmd, "outputs") == 0) {
    JsonArray arr = doc["config"].as<JsonArray>();
    for (int i = 0; i < 5 && i < (int)arr.size(); i++) {
      JsonObject o = arr[i];
      cfg.outputs[i].func         = FUNC_IDX(o["func"] | "None");
      cfg.outputs[i].ev1.trigger  = TRIG_IDX(o["ev1"]  | "None");
      cfg.outputs[i].ev1.action   = ACT_IDX (o["a1"]   | "None");
      cfg.outputs[i].ev1.delaySec = o["d1"] | 0;
      cfg.outputs[i].ev2.trigger  = TRIG_IDX(o["ev2"]  | "None");
      cfg.outputs[i].ev2.action   = ACT_IDX (o["a2"]   | "None");
      cfg.outputs[i].ev2.delaySec = o["d2"] | 0;
    }
    cfgSave();
    sendOutputsConfig();   // echo back so UI confirms
  }
  // ── advanced config ────────────────────────────────────
  else if (strcmp(cmd, "advanced") == 0) {
    JsonObject v = doc["vars"].as<JsonObject>();
    cfg.numLeds         = v["NUM_LEDS"]             | cfg.numLeds;
    cfg.numBrakeLeds    = v["NUM_BRAKE_LEDS"]        | cfg.numBrakeLeds;
    cfg.engineRpmThr    = v["ENGINE_RPM_THRESHOLD"]  | cfg.engineRpmThr;
    cfg.strobeWindowSec = v["STROBE_WINDOW_MS"]      | cfg.strobeWindowSec;
    cfg.strobeDurSec    = v["STROBE_DURATION_MS"]    | cfg.strobeDurSec;
    cfg.strobePeriodSec = v["STROBE_PERIOD_MS"]      | cfg.strobePeriodSec;
    cfg.waveStepMs      = v["WAVE_STEP_MS"]          | cfg.waveStepMs;
    cfg.waveHoldMs      = v["WAVE_HOLD_MS"]          | cfg.waveHoldMs;
    cfg.wavePauseMs     = v["WAVE_PAUSE_MS"]         | cfg.wavePauseMs;
    ledsL.updateLength(cfg.numLeds);
    ledsR.updateLength(cfg.numLeds);
    cfgSave();
    sendAdvancedConfig();
  }
  // ── read requests ──────────────────────────────────────
  else if (strcmp(cmd, "read_outputs")  == 0) { sendOutputsConfig();  }
  else if (strcmp(cmd, "read_advanced") == 0) { sendAdvancedConfig(); }
  else if (strcmp(cmd, "read_startup")  == 0) {
    sendBLE("{\"cmd\":\"startup_cfg\",\"value\":" + String(cfg.startupSeq) + "}");
  }
  // ── test event ─────────────────────────────────────────
  else if (strcmp(cmd, "test_event") == 0) {
    testOutputEvent(doc["output"] | 0, doc["event"] | 1);
  }
  // ── change PIN ─────────────────────────────────────────
  else if (strcmp(cmd, "change_pin") == 0) {
    const char* p = doc["pin"] | "";
    bool valid = (strlen(p) == 4
                  && isdigit((uint8_t)p[0]) && isdigit((uint8_t)p[1])
                  && isdigit((uint8_t)p[2]) && isdigit((uint8_t)p[3]));
    if (valid) {
      strncpy(cfg.pin, p, 5);
      cfgSave();
      sendBLE("{\"cmd\":\"pin_changed\",\"ok\":true}");
      Serial.print("[BLE] PIN changed to "); Serial.println(cfg.pin);
    } else {
      sendBLE("{\"cmd\":\"pin_changed\",\"ok\":false}");
    }
  }
  // ── sim — test events from HTML panel ──────────────────
  else if (strcmp(cmd, "sim") == 0) {
    const char* ev  = doc["event"] | "";
    bool        sta = doc["state"]  | false;
    unsigned long now = millis();
    unsigned long strobeWindowMs = (unsigned long)(cfg.strobeWindowSec * 1000.0f);
    unsigned long strobeDurMs    = (unsigned long)(cfg.strobeDurSec    * 1000.0f);

    if (strcmp(ev, "power_on") == 0) {
      if (sta) runStartupAnimation(cfg.startupSeq);
    }
    else if (strcmp(ev, "engine") == 0) {
      if (sta && !stateEngine) { engineStartTime = now; Serial.println(">>> [SIM] Engine RUNNING"); }
      else if (!sta && stateEngine)  Serial.println(">>> [SIM] Engine STOPPED");
      stateEngine = sta;
    }
    else if (strcmp(ev, "high_beam") == 0) {
      if (sta && !stateHighBeam) {
        Serial.println(">>> [SIM] High Beam click");
        if (now - firstHBPressTime > strobeWindowMs) {
          hbPressCount = 1; firstHBPressTime = now;
        } else {
          hbPressCount++;
          if (hbPressCount >= 3) {
            strobeActive = true; strobeEndTime = now + strobeDurMs;
            hbPressCount = 0; Serial.println(">>> [SIM] STROBE TRIGGERED");
          }
        }
      }
      stateHighBeam = sta;
    }
    else if (strcmp(ev, "brake")        == 0) { stateBrake  = sta; Serial.print(">>> [SIM] Brake ");         Serial.println(sta ? "ON" : "OFF"); }
    else if (strcmp(ev, "signal_left")  == 0) { stateLeft   = sta; Serial.print(">>> [SIM] Signal Left ");   Serial.println(sta ? "ON" : "OFF"); }
    else if (strcmp(ev, "signal_right") == 0) { stateRight  = sta; Serial.print(">>> [SIM] Signal Right ");  Serial.println(sta ? "ON" : "OFF"); }
    else if (strcmp(ev, "hazard")       == 0) { stateLeft = stateRight = sta; Serial.print(">>> [SIM] Hazard "); Serial.println(sta ? "ON" : "OFF"); }
    else if (strcmp(ev, "horn")         == 0) { stateHorn = sta; Serial.print(">>> [SIM] Horn "); Serial.println(sta ? "ON" : "OFF"); }
  }
}

void processBleWrites() {
  if (!bleChar.written()) return;
  int len = bleChar.valueLength();
  if (len <= 0) return;

  // Accumulate into buffer — full command ends with '\n'
  for (int i = 0; i < len; i++)
    bleBuf += (char)bleChar.value()[i];

  int nl;
  while ((nl = bleBuf.indexOf('\n')) >= 0) {
    String line = bleBuf.substring(0, nl);
    bleBuf = bleBuf.substring(nl + 1);
    line.trim();
    if (line.length()) handleBleCommand(line);
  }
}

// ──────────────────────────────────────────────────────────
// SETUP
// ──────────────────────────────────────────────────────────
void setup() {
  // 1. Hold CAN TX HIGH before anything else
  pinMode(TX_PIN, OUTPUT);
  digitalWrite(TX_PIN, HIGH);

  // 2. DC-DC converter stabilization
  delay(2000);

  // 3. CAN FIRST — must be running before NeoPixel show() calls
  twai_general_config_t g_config = TWAI_GENERAL_CONFIG_DEFAULT(
      (gpio_num_t)TX_PIN, (gpio_num_t)RX_PIN, TWAI_MODE_LISTEN_ONLY);
  twai_timing_config_t t_config = TWAI_TIMING_CONFIG_500KBITS();
  twai_filter_config_t f_config = TWAI_FILTER_CONFIG_ACCEPT_ALL();
  twai_driver_install(&g_config, &t_config, &f_config);
  twai_start();

  // 4. Serial
  Serial.begin(115200);
  Serial.println("========================================");
  Serial.println("     BMW R1300GS  —  EasierCan  v2      ");
  Serial.println("========================================");

  // 5. Load config from NVS (or apply defaults)
  cfgSetDefaults();
  if (cfgLoad()) {
    Serial.println("[NVS] Config loaded.");
  } else {
    Serial.println("[NVS] No saved config — using defaults.");
  }

  // 6. MOSFET output pins — all OFF
  pinMode(FOG_LEFT_PIN,  OUTPUT);  digitalWrite(FOG_LEFT_PIN,  LOW);
  pinMode(FOG_RIGHT_PIN, OUTPUT);  digitalWrite(FOG_RIGHT_PIN, LOW);
  pinMode(AIR_HORN_PIN,  OUTPUT);  digitalWrite(AIR_HORN_PIN,  LOW);

  // 7. NeoPixels (length from cfg)
  ledsL.updateLength(cfg.numLeds);
  ledsR.updateLength(cfg.numLeds);
  ledsL.begin();  ledsR.begin();
  ledsL.setBrightness(100);  ledsR.setBrightness(100);
  ledsL.clear();  ledsR.clear();
  ledsL.show();   ledsR.show();

  // 8. Startup animation
  randomSeed(analogRead(0));
  runStartupAnimation(cfg.startupSeq);

  // 9. BLE — after animation so CAN is stable
  if (!BLE.begin()) {
    Serial.println("[BLE] Failed to start — continuing without BLE.");
  } else {
    BLE.setLocalName(BLE_DEVICE_NAME);
    BLE.setAdvertisedService(bleService);
    bleService.addCharacteristic(bleChar);
    BLE.addService(bleService);
    BLE.advertise();
    Serial.println("[BLE] Advertising as \"" BLE_DEVICE_NAME "\"");
  }
}

// ──────────────────────────────────────────────────────────
// STARTUP ANIMATION SHARED HELPERS
// ──────────────────────────────────────────────────────────
static inline void aSH()         { ledsL.show();  ledsR.show(); }
static inline void aBR(uint8_t b){ ledsL.setBrightness(b); ledsR.setBrightness(b); }
static inline void aCL()         { ledsL.clear(); ledsR.clear(); aSH(); }
static inline uint32_t aRGB (uint8_t r,uint8_t g,uint8_t b)
  { return ledsL.Color(r,g,b,0); }
static inline uint32_t aRGBW(uint8_t r,uint8_t g,uint8_t b,uint8_t w)
  { return ledsL.Color(r,g,b,w); }
static inline void aSetAll(uint32_t c) {
  for (int i=0;i<(int)cfg.numLeds;i++){ledsL.setPixelColor(i,c);ledsR.setPixelColor(i,c);}
}
static inline void aSetPx(int i, uint32_t c) {
  if (i>=0 && i<(int)cfg.numLeds){ledsL.setPixelColor(i,c);ledsR.setPixelColor(i,c);}
}
// Scale a packed WRGB colour by 0-255 without touching setBrightness()
static inline uint32_t aScale(uint32_t c, uint8_t s) {
  return ledsL.Color(
    ((c >> 16) & 0xFF) * s / 255,
    ((c >>  8) & 0xFF) * s / 255,
    ( c        & 0xFF) * s / 255,
    ((c >> 24) & 0xFF) * s / 255);
}
static inline void aFadeAll(uint32_t base, uint8_t s) { aSetAll(aScale(base,s)); aSH(); }
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
void loop() {
  // Reset auth flag when the central disconnects
  static bool wasConnected = false;
  bool nowConnected = BLE.connected();
  if (wasConnected && !nowConnected) {
    bleAuthenticated = false;
    Serial.println("[BLE] Disconnected — auth reset.");
  }
  wasConnected = nowConnected;

  // Process BLE events
  BLE.poll();
  processBleWrites();

  // CAN receive
  twai_message_t message;
  if (twai_receive(&message, pdMS_TO_TICKS(1)) == ESP_OK) {
    messagesReceivedInCycle++;
    unsigned long now = millis();

    // ENGINE RPM — 0x10C
    if (message.identifier == ID_BMSK) {
      engineRpm = ((uint16_t)message.data[2] * 256 + message.data[1]) / 4;
      bool running = (engineRpm > cfg.engineRpmThr);
      if (running && !stateEngine) {
        engineStartTime = now;
        Serial.println(">>> Engine RUNNING — fog timer started");
      } else if (!running && stateEngine) {
        Serial.println(">>> Engine STOPPED");
      }
      stateEngine = running;
    }

    // HIGH BEAM — triple press → strobe
    if (message.identifier == ID_HIGH_BEAM) {
      unsigned long strobeWindowMs = (unsigned long)(cfg.strobeWindowSec * 1000.0f);
      unsigned long strobeDurMs    = (unsigned long)(cfg.strobeDurSec    * 1000.0f);
      bool currentHB = ((message.data[6] & 0x10) == 0);
      if (currentHB && !stateHighBeam) {
        Serial.println(">>> High Beam click");
        if (now - firstHBPressTime > strobeWindowMs) {
          hbPressCount = 1; firstHBPressTime = now;
        } else {
          hbPressCount++;
          if (hbPressCount >= 3) {
            strobeActive  = true;
            strobeEndTime = now + strobeDurMs;
            hbPressCount  = 0;
            Serial.println(">>> STROBE TRIGGERED");
          }
        }
      }
      stateHighBeam = currentHB;
    }

    // SWITCHES — turn signals & brake
    if (message.identifier == ID_SWITCHES) {
      uint8_t d0 = message.data[0];

      bool l = (d0 & 0x04);
      if (l != stateLeft)  { stateLeft  = l; Serial.print(">>> Left Signal ");  Serial.println(l ? "ON":"OFF"); }

      bool r = (d0 & 0x08);
      if (r != stateRight) { stateRight = r; Serial.print(">>> Right Signal "); Serial.println(r ? "ON":"OFF"); }

      bool b = (d0 & 0x20);
      if (b != stateBrake) { stateBrake = b; Serial.print(">>> Brake ");        Serial.println(b ? "ON":"OFF"); }
    }
  }

  applyLogic();
}

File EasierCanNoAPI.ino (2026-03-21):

// ============================================================
//  EasierCan.ino  —  BMW R1300GS CAN Bus Controller
//  Features: Knight Rider startup, brake light,
//            wave sequential turn signals,
//            MOSFET fog lights (on when engine running >5s,
//            blink with active turn signal),
//            strobe mode (triple high-beam press → 2s rapid flash)
// ============================================================

#include <Adafruit_NeoPixel.h>
#include "driver/twai.h"

// ==========================================
// HARDWARE PINS
// ==========================================
#define RX_PIN        GPIO_NUM_9   // D6
#define TX_PIN        GPIO_NUM_7   // D4
#define LED_PIN_LEFT  6            // D3
#define LED_PIN_RIGHT 8            // D5
#define NUM_LEDS      9

// MOSFET output pins
#define FOG_LEFT_PIN  A5           // GPIO 12
#define FOG_RIGHT_PIN A1           // GPIO 2
#define AIR_HORN_PIN  A3           // GPIO 4

// ==========================================
// CAN BUS IDs
// ==========================================
// 0x10C — BMSK engine control module, 10ms cycle
//   RPM  = (data[2] * 256 + data[1]) / 4
//   data[0] = throttle position
//   data[3] = clutch / kill switch (high nibble)
//   data[4] = side stand (high nibble)
#define ID_BMSK      0x10C
#define ID_HIGH_BEAM 0x2D0
#define ID_SWITCHES  0x2D2

// ==========================================
// TIMING CONSTANTS
// ==========================================
// Fog lights come on this many ms after engine starts running
#define FOG_ENGINE_DELAY_MS  5000UL
// RPM threshold for "engine running"
#define ENGINE_RPM_THRESHOLD  50

// Strobe: 3 high-beam presses within this window triggers strobe
#define STROBE_WINDOW_MS  2000UL
// How long strobe runs
#define STROBE_DURATION_MS 2000UL
// Strobe blink period (50% duty cycle)
#define STROBE_PERIOD_MS    100UL

// ==========================================
// WAVE SEQUENTIAL INDICATOR TIMING
// ==========================================
#define WAVE_STEP_MS   80    // ms per LED during fill
#define WAVE_HOLD_MS  160    // ms hold all on
#define WAVE_PAUSE_MS 320    // ms all off before next cycle

// ==========================================
// STATE
// ==========================================
bool stateLeft     = false;
bool stateBrake    = false;
bool stateRight    = false;
bool stateHighBeam = false;
bool stateEngine   = false;

uint16_t      engineRpm        = 0;
unsigned long engineStartTime  = 0;

// Strobe state
bool          strobeActive     = false;
unsigned long strobeEndTime    = 0;
int           hbPressCount     = 0;
unsigned long firstHBPressTime = 0;

unsigned long lastDebugPrint         = 0;
unsigned int  messagesReceivedInCycle = 0;

Adafruit_NeoPixel ledsL(NUM_LEDS, LED_PIN_LEFT,  NEO_GRBW + NEO_KHZ800);
Adafruit_NeoPixel ledsR(NUM_LEDS, LED_PIN_RIGHT, NEO_GRBW + NEO_KHZ800);

// ==========================================
// SETUP
// ==========================================
void setup() {
  // Hold CAN TX HIGH before anything else
  pinMode(TX_PIN, OUTPUT);
  digitalWrite(TX_PIN, HIGH);

  delay(2000);  // DC-DC converter stabilization

  // CAN FIRST — must be running before NeoPixel show() calls
  twai_general_config_t g_config = TWAI_GENERAL_CONFIG_DEFAULT(
      (gpio_num_t)TX_PIN, (gpio_num_t)RX_PIN, TWAI_MODE_LISTEN_ONLY);
  twai_timing_config_t t_config = TWAI_TIMING_CONFIG_500KBITS();
  twai_filter_config_t f_config = TWAI_FILTER_CONFIG_ACCEPT_ALL();
  twai_driver_install(&g_config, &t_config, &f_config);
  twai_start();

  Serial.begin(115200);
  Serial.println("========================================");
  Serial.println("      BMW R1300GS  —  EasierCan          ");
  Serial.println("  Fogs on 15s timer, blink with signal   ");
  Serial.println("========================================");

  // MOSFET output pins — all OFF at startup
  pinMode(FOG_LEFT_PIN,  OUTPUT);  digitalWrite(FOG_LEFT_PIN,  LOW);
  pinMode(FOG_RIGHT_PIN, OUTPUT);  digitalWrite(FOG_RIGHT_PIN, LOW);
  pinMode(AIR_HORN_PIN,  OUTPUT);  digitalWrite(AIR_HORN_PIN,  LOW);

  // NeoPixels after CAN
  ledsL.begin();
  ledsR.begin();
  ledsL.setBrightness(100);
  ledsR.setBrightness(100);
  ledsL.clear();
  ledsR.clear();
  ledsL.show();
  ledsR.show();

  knightRiderStartup();
}

// ==========================================
// STARTUP: KNIGHT RIDER ANIMATION
// ==========================================
void knightRiderStartup() {
  const uint8_t trail[]   = { 255, 110, 35, 10 };
  const int     TRAIL_LEN = 4;
  const int     STEP_MS   = 38;
  const int     PASSES    = 4;

  for (int pass = 0; pass < PASSES; pass++) {
    bool forward = (pass % 2 == 0);
    int  start   = forward ? 0 : NUM_LEDS - 1;
    int  end_pos = forward ? NUM_LEDS : -1;
    int  dir     = forward ? 1 : -1;

    for (int pos = start; pos != end_pos; pos += dir) {
      ledsL.clear();
      ledsR.clear();
      for (int t = 0; t < TRAIL_LEN; t++) {
        int idx = pos - (dir * t);
        if (idx >= 0 && idx < NUM_LEDS) {
          uint32_t c = ledsL.Color(trail[t], 0, 0, 0);
          ledsL.setPixelColor(idx, c);
          ledsR.setPixelColor(idx, c);
        }
      }
      ledsL.show();
      ledsR.show();
      delay(STEP_MS);
    }
  }

  for (int b = 100; b >= 0; b -= 5) {
    ledsL.setBrightness(b);
    ledsR.setBrightness(b);
    ledsL.show();
    ledsR.show();
    delay(18);
  }

  ledsL.clear();  ledsR.clear();
  ledsL.setBrightness(100);
  ledsR.setBrightness(100);
  ledsL.show();   ledsR.show();
  delay(200);
}

// ==========================================
// WAVE SEQUENTIAL INDICATOR
// ==========================================
void drawWaveIndicator(Adafruit_NeoPixel &strip, bool active) {
  const int IND_COUNT = NUM_LEDS - 3;  // 6 LEDs (indices 3–8)

  if (!active) {
    for (int i = 3; i < NUM_LEDS; i++) strip.setPixelColor(i, 0);
    return;
  }

  const unsigned long CYCLE = (unsigned long)(IND_COUNT * WAVE_STEP_MS)
                              + WAVE_HOLD_MS + WAVE_PAUSE_MS;
  unsigned long phase = millis() % CYCLE;

  int litCount;
  if (phase < (unsigned long)(IND_COUNT * WAVE_STEP_MS)) {
    litCount = (int)(phase / WAVE_STEP_MS) + 1;
  } else if (phase < (unsigned long)(IND_COUNT * WAVE_STEP_MS + WAVE_HOLD_MS)) {
    litCount = IND_COUNT;
  } else {
    litCount = 0;
  }

  for (int i = 3; i < NUM_LEDS; i++) {
    strip.setPixelColor(i, (i < 3 + litCount) ? strip.Color(255, 50, 0, 0) : 0);
  }
}
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
